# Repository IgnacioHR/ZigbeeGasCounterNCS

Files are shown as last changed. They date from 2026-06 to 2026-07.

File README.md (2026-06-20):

# Zigbee Gas Counter for nRF52840

This project is a DIY Zigbee gas counter based on the Nordic Semiconductor nRF52840 platform.

It measures gas consumption by detecting pulses from a mechanical gas meter using a reed sensor, keeps an internal cumulative counter, and exposes the data through Zigbee so it can be used from Zigbee2MQTT and Home Assistant.

The device is designed to run from batteries for long periods of time and to keep counting even if Zigbee2MQTT, Home Assistant, or the Zigbee coordinator are temporarily unavailable.

## Features

- Zigbee gas consumption tracking in cubic meters (m³).
- Internal cumulative counter stored by the device.
- Battery-powered low-power design.
- Zigbee radio enabled only when needed.
- Dual 18650 battery holder with batteries connected in parallel.
- Battery replacement without interrupting device operation.
- Battery voltage and battery percentage reporting.
- Main button with gesture recognition.
- Zigbee OTA firmware updates.
- MCUboot-based bootloader.
- Source code available for both:
  - Seeed Studio XIAO nRF52840
  - Nordic Semiconductor nRF52840 DK
- 3D-printable enclosure and battery holder.
- Optional gas flow measurement.
- Optional battery measurement and reporting.
- Configurable deep-sleep or light-sleep behavior.
- Optional manufacturer-specific attribute for setting the counter value.

## Hardware Pictures

### Fully assembled device

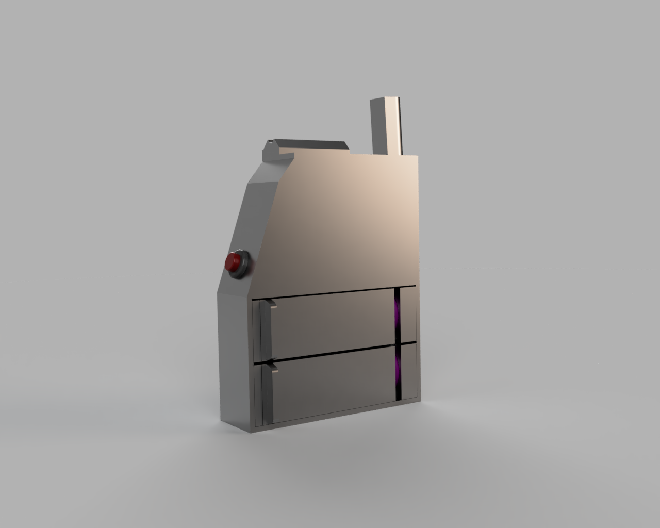
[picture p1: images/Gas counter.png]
Gas counter


### Cover removed

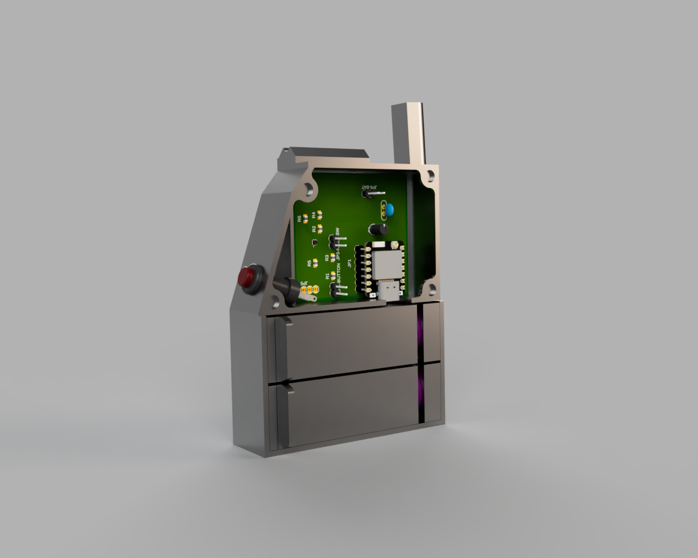
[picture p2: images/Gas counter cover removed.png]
Gas counter cover removed


### Cover removed and bottom battery extracted

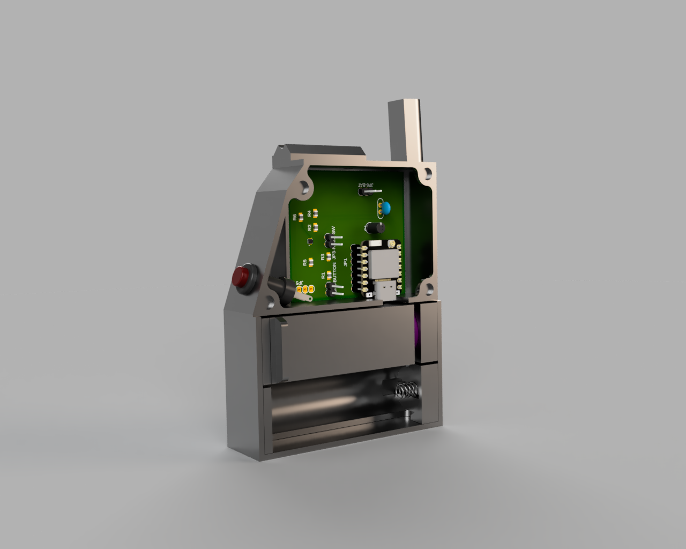
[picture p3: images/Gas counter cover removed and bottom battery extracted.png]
Gas counter cover removed and bottom battery extracted


## Supported Boards

This repository contains source code for two hardware targets.

### Seeed Studio XIAO nRF52840

This is the board used in the actual deployed gas counter device.

The XIAO nRF52840 version is optimized for low-power battery operation and is intended to be installed next to the gas meter inside the custom 3D-printed enclosure.

### Nordic Semiconductor nRF52840 DK

The nRF52840 DK version is used for development, debugging, and testing.

It is useful while developing new firmware features because it provides easier access to SWD, buttons, LEDs, and debug interfaces.

## Zigbee Device Type and Low-Power Operation

In a Zigbee network, devices are usually classified as coordinators, routers, or end devices.

This project behaves as a low-power end device, but with a very specific operating model: the Zigbee radio is normally kept off to save energy, and it is enabled only when needed.

In normal operation, the device wakes the Zigbee radio every 10 gas meter pulses. This allows the counter to keep accurate local measurements while avoiding the power cost of keeping the radio permanently active.

The device can also enable the Zigbee radio when the main button is pressed. This is useful before starting an OTA update, writing the counter value, or forcing an immediate report.

The nRF52840 does not include a dedicated real-time clock that can be used as an absolute wall-clock source while the device is sleeping. For this reason, the firmware uses time information obtained from the Zigbee coordinator to maintain internal timing-related state, such as calculating how long it has been since the battery was last measured.

## Bootloader and Firmware Updates

The firmware boots through MCUboot.

Because of this, the initial firmware must be programmed using an SWD programmer/debugger. Once the bootloader and the first application image have been written, future firmware updates can be performed over Zigbee OTA.

A typical deployment process is:

1. Build the firmware with MCUboot enabled.
2. Flash the complete merged image through SWD.
3. Pair the device with the Zigbee network.
4. Use Zigbee OTA for future firmware updates.

When using OTA, the new image is first downloaded through Zigbee, then MCUboot swaps the image on reboot. The new firmware confirms itself after it has successfully started and recovered Zigbee connectivity.

## How It Works

1. The gas meter has a rotating part with a magnet.
2. A reed sensor detects each rotation or pulse.
3. Each pulse represents a known gas volume.
4. The nRF52840 firmware updates the internal cumulative counter.
5. The device periodically enables the Zigbee radio and reports the accumulated data.
6. The device exposes the value through the Zigbee Metering cluster.
7. Zigbee2MQTT receives the data and forwards it to Home Assistant.

The device does not depend on Home Assistant being online in order to keep counting. The counter is maintained internally by the device.

## Main Button Gestures

The device has one main button. Multiple gestures are recognized and mapped to device actions.

### Button press

Pressing the button, even as part of another gesture, enables the Zigbee radio for approximately one minute and transmits the currently available data.

Use this before performing actions that require the device to be reachable, such as:

- Starting an OTA firmware update.
- Writing a new gas counter value from Zigbee2MQTT.
- Requesting immediate reports.

The Zigbee radio may take around 10 seconds to reconnect to the coordinator, so wait a short time after pressing the button before sending Zigbee commands.

### Single click

A single click is the most common user action.

It performs the following actions:

- Reports all reportable attributes, including gas counter and battery information.
- Forces a battery level measurement.
- Clears and reevaluates possible warning or fault conditions.

### Triple click

A triple click resets the device.

The gas counter value is not intentionally cleared by this action.

### Five quick clicks

Five quick button clicks make the device leave the current Zigbee network and start the join process again.

Use this when you want to move the device to another Zigbee network or force a clean rejoin.

## Battery System

The device uses two 18650 batteries connected in parallel.

The current prototype uses two 3400 mAh cells, providing a total nominal capacity of approximately 6800 mAh.

The enclosure and battery holder are designed so one battery can be removed and charged externally while the device continues running from the other battery.

Always keep at least one battery installed. This prevents the device from losing power and helps avoid missed gas meter pulses during battery replacement.

## Battery Life

The device is designed for very low power operation.

Battery voltage and percentage are measured and reported at least once every 12 hours. They can also be refreshed manually with a single button click.

With two 3400 mAh batteries connected in parallel, the expected runtime is several months. The final runtime is still being measured.

## Zigbee Integration

The device is intended to work with:

- Zigbee2MQTT
- Home Assistant

The firmware exposes gas consumption through standard Zigbee clusters where possible, while also using custom manufacturer-specific attributes for device-specific operations such as setting the current counter value.

The manufacturer information used by the device is:

- Manufacturer name: `Custom devices (DiY)`
- Model identifier: `MiCASAGasCounter`
- Manufacturer code: `0x8888`

The manufacturer code is arbitrary and intended for this DIY project.

## Setting the Counter Value

If enabled in `include/zb_features.h`, the firmware includes a manufacturer-specific attribute in the Metering cluster that allows the cumulative counter value to be set from Zigbee2MQTT.

This is useful when installing the device for the first time, because the internal counter can be synchronized with the physical gas meter reading.

Before writing the counter value, press the main button to wake the Zigbee radio and wait a few seconds for the device to reconnect.

## OTA Firmware Updates

The firmware supports Zigbee OTA updates.

Before starting an OTA update:

1. Press the main button.
2. Wait approximately 10 seconds for Zigbee connectivity to be restored.
3. Start the OTA update from Zigbee2MQTT.

After the OTA transfer completes, the device reboots. MCUboot then boots the new image. The firmware confirms the new image only after the device has started successfully and has had time to reconnect to the Zigbee network.

This reduces the risk of permanently confirming a firmware image that boots but cannot recover basic Zigbee functionality.

## Required Hardware

To build the XIAO-based version, you need:

- Seeed Studio XIAO nRF52840.
- Magnetic reed sensor.
- Two 18650 batteries.
- Battery contacts or battery holder hardware.
- Main push button.
- 3D-printed enclosure.
- SWD programmer/debugger for the initial firmware flash.
- 18 small magnets 4.75mm x 1.5mm (see the `hardware` folder)

For development, the Nordic Semiconductor nRF52840 DK can be used instead of the XIAO board.

## Software Requirements

- nRF Connect SDK.
- Zephyr RTOS.
- MCUboot.
- Zigbee2MQTT.
- Home Assistant, optional but recommended.
- SWD flashing/debugging tools.

## Configuration Options

Some firmware features can be enabled or disabled from:

```text
include/zb_features.h
```

The default configuration is tuned for my own use case: a battery-powered gas counter using deep sleep for maximum battery life.

If your use case is different, review this file before building the firmware.

### Gas flow measurement

The firmware can optionally expose gas flow measurement.

This requires more frequent Zigbee communication, so it is not recommended for battery-powered deployments. It can be useful if the device is externally powered or if battery life is not a concern.

### Battery measurement

Battery voltage and battery percentage reporting can be enabled or disabled.

If the device is not powered from batteries, this feature can be disabled.

### Deep sleep

Deep sleep provides the lowest power consumption.

This is the configuration used by my deployed device. In this mode, the device keeps counting locally and only enables the Zigbee radio when needed, such as after a configured number of gas meter pulses or when the main button is pressed.

This mode is recommended for long-term battery-powered operation.

### Light sleep

Light sleep implements a more conventional Zigbee end-device behavior.

In this mode, the device keeps the Zigbee radio enabled and does not enter deep sleep. This makes the device more readily available on the Zigbee network, but it consumes significantly more power.

This mode may be useful during development, testing, or externally powered deployments.

### Counter write attribute

The firmware includes an optional manufacturer-specific attribute that allows the gas counter value to be written from Zigbee2MQTT.

This is useful when installing the device because the internal counter can be synchronized with the physical gas meter reading.

If this feature is disabled, the counter value cannot be written remotely.

## Building and Flashing

The project is built with nRF Connect SDK and Zephyr.

The firmware uses MCUboot, so the first flash should write the complete merged image, not only the application image.

A typical SWD flashing process writes:

```bash
merged.hex
```

After the initial programming, future updates can be delivered using Zigbee OTA.

## 3D-Printed Hardware

The repository includes STEP files for the enclosure and battery holder.

The 3D-printed hardware is designed to hold:

- The main electronics board.
- Two 18650 batteries.
- The main button.
- The reed sensor.
- The removable cover.

The mechanical design is intended to make battery replacement possible without fully powering down the device.

## Project Status

This project is the nRF52840 evolution of the original ESP32-C6 Zigbee gas counter.

The ESP32-C6 version proved the concept and helped validate the Zigbee gas counter design. The nRF52840 version focuses on improving power consumption, OTA robustness, and long-term reliability.

Current status:

- Pulse counting works.
- Zigbee integration works.
- Battery reporting works.
- Main button gesture handling works.
- Zigbee OTA works.
- MCUboot image confirmation is handled by the application after startup.
- Long-term battery life is still being measured.

## Relation to the ESP32-C6 Version

This project is based on lessons learned from the previous ESP32-C6 implementation.

The ESP32-C6 version proved the concept and helped validate the Zigbee gas counter design. The nRF52840 version focuses on improving power consumption, OTA robustness, and long-term reliability.

## Customization

The same approach can be adapted to other pulse-based meters, such as:

- Water meters.
- Electricity meters with pulse output.
- Other mechanical counters with a magnet or reed-compatible pulse source.

The main changes would be the unit of measurement, the pulse-to-volume conversion factor, and the Zigbee attributes exposed by the firmware.

## Contributing

Contributions, suggestions, and improvements are welcome.

Areas where contributions may be useful include:

- Reviewing the low-power design.
- Improving Zigbee2MQTT converter support.
- Reviewing hardware design.
- Testing other reed sensors or enclosure variants.
- Improving documentation.

## Acknowledgments

I would like to thank Nordic Semiconductor for the excellent online training courses and documentation. They helped me start development on the nRF52840 platform much faster than I expected.

I also want to acknowledge the invaluable help of ChatGPT during the development process. It helped me move faster, debug complex issues, and explore solutions while building this project.

## License

This project is shared under the Creative Commons Attribution-NonCommercial-ShareAlike 4.0 International License.

You are free to copy, modify, and adapt the project for personal or non-commercial use, provided that you give appropriate credit and share derived work under the same license.

Commercial use is not allowed.

See the license details here:

[Creative Commons Attribution-NonCommercial-ShareAlike 4.0 International](https://creativecommons.org/licenses/by-nc-sa/4.0/deed.en)

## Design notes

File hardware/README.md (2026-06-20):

# Hardware

This directory contains the 3D-printable parts used to assemble the gas counter enclosure.

The enclosure is designed to hold:

- The main electronics board
- Two 18650 batteries connected in parallel
- The main push button
- The reed sensor used to detect gas meter pulses

The main body has an opening at the top for inserting a 5 mm × 10 mm threaded insert, which is used to attach the enclosure to the gas meter. The triangular-looking part with a cylindrical section in the middle is designed to hold the reed sensor in the correct position.

## Power Source

The device is powered by two 18650 batteries connected in parallel.

The reason for using two batteries is to make battery maintenance easier: one battery can be removed and charged externally while the device continues running from the other battery.

Always keep at least one battery installed while replacing or charging the other one. This prevents the device from losing power and helps ensure that no reed sensor pulses are missed during battery maintenance.

## Materials

All parts were printed in PETG.

PETG was chosen because it provides a good balance between mechanical strength, durability, and ease of printing.

## Magnets

Some parts include small cylindrical holes measuring approximately 4.75 mm × 1.65 mm. These holes are intended for small magnets.

The magnets are used to hold the battery holder, main body, and cover plate together without requiring screws for those parts.

## License

The models are shared in STEP format so they can be adapted to different setups or modified for your own needs.

These hardware models are licensed under the **Creative Commons Attribution-NonCommercial-ShareAlike 4.0 International License**.

You are free to copy, modify, and adapt the models for personal or non-commercial use, provided that you give appropriate credit and share any derived work under the same license.

Commercial use is not allowed.

## Downloads

- [Gas counter - Main body](Gas%20counter%20main%20body.step)
- [Gas counter - Top cover](Gas%20counter%20top%20cover.step)
- [Battery holder - Top side](Battery%20holder%20-%20top%20side.step)
- [Battery holder - Bottom side](Battery%20holder%20-%20bottom%20side.step)
- [Battery holder - Lock for hole under negative pole](Battery%20holder%20-%20lock%20for%20hole%20under%20negative%20pole.step)
- [Battery holder - Lock for hole under positive pole](Battery%20holder%20-%20lock%20for%20hole%20under%20positive%20pole.step)

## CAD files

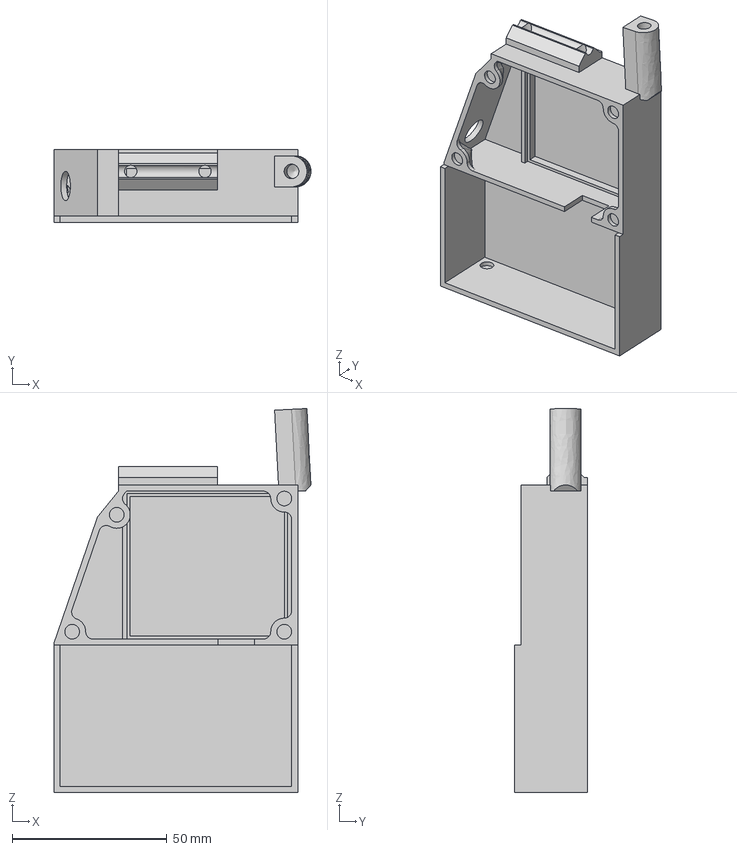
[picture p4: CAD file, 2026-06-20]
hardware/Gas counter main body.step
83.1 x 23.4 x 124.1 mm

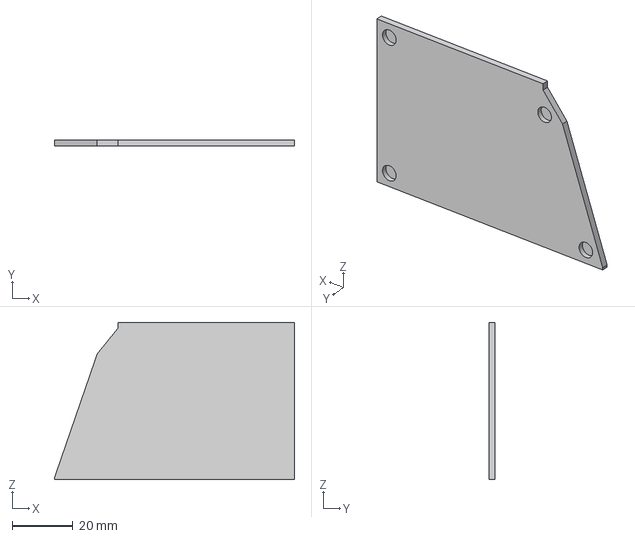
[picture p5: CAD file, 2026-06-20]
hardware/Gas counter top cover.step
78.8 x 2.00 x 51.7 mm

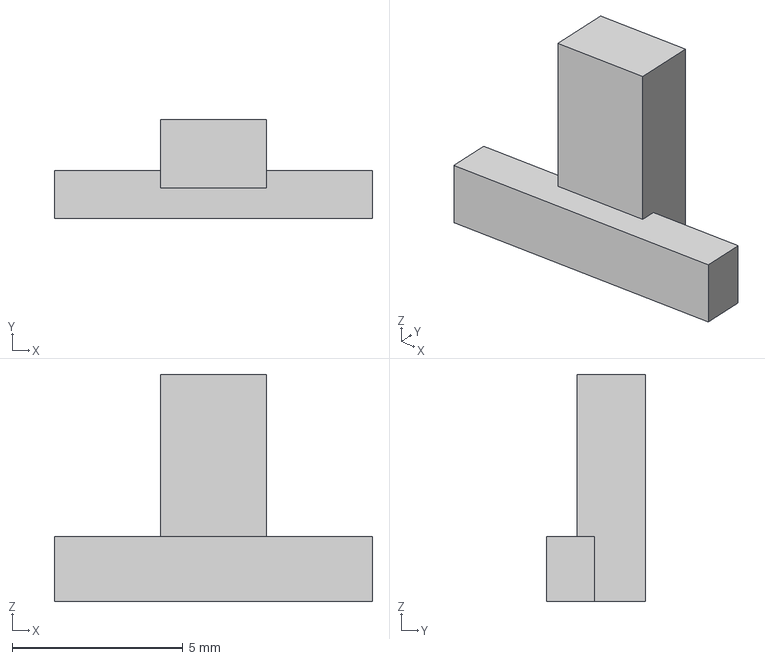
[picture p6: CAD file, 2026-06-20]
hardware/Battery holder - lock for hole under positive pole.step
9.30 x 2.90 x 6.65 mm

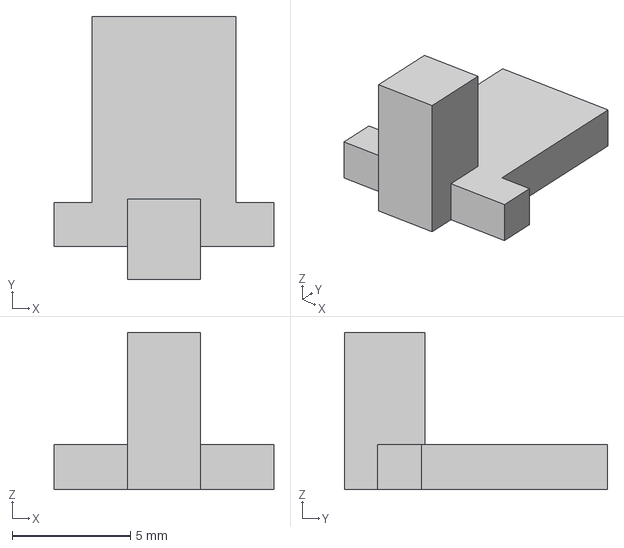
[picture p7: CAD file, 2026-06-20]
hardware/Battery holder - lock for hole under negative pole.step
9.30 x 11.1 x 6.65 mm

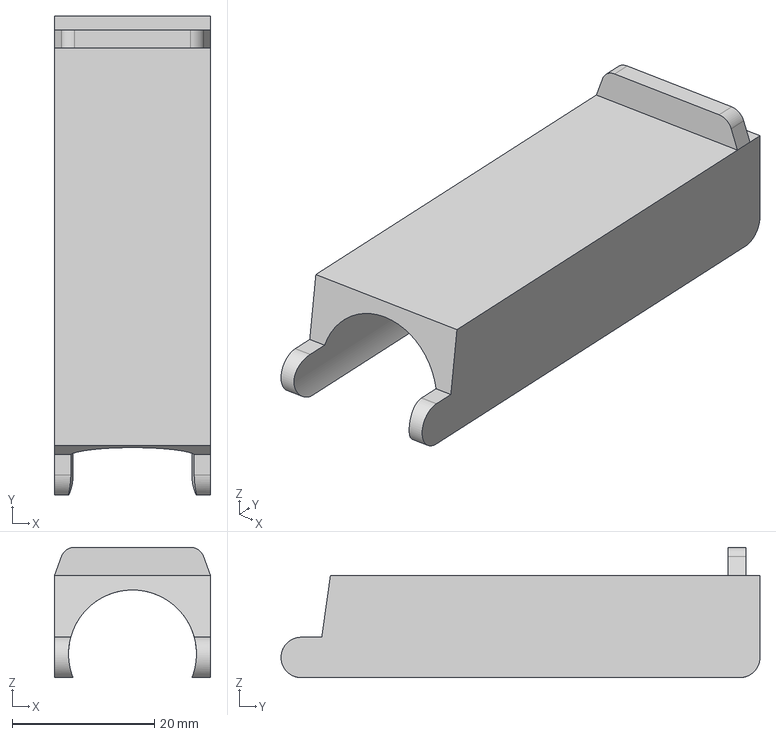
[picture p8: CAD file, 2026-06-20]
hardware/Battery holder - top side.step
22.0 x 67.4 x 18.4 mm

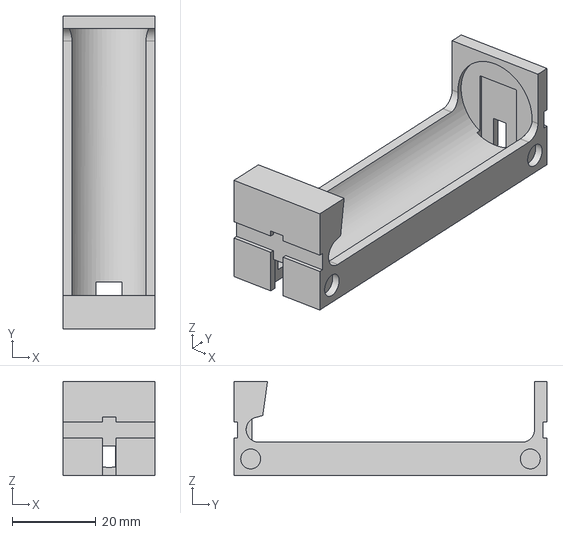
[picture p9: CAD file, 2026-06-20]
hardware/Battery holder - bottom side.step
22.0 x 74.6 x 22.5 mm

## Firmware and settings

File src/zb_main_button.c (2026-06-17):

/*
 * Zigbee Gas Counter - An open-source Zigbee gas counter project.
 * Copyright (c) 2026 Ignacio Hernández-Ros.
 *
 * This work is licensed under the Creative Commons Attribution-NonCommercial-ShareAlike 4.0
 * International License. To view a copy of this license, visit
 * https://creativecommons.org/licenses/by-nc-sa/4.0/
 *
 * You may use, modify, and share this work for personal and non-commercial purposes, as long
 * as you credit the original author(s) and share any derivatives under the same license.
 */

#include <zephyr/kernel.h>
#include <zephyr/device.h>
#include <zephyr/devicetree.h>
#include <zephyr/drivers/gpio.h>
#include <zephyr/sys/reboot.h>

#include <zephyr/logging/log.h>
LOG_MODULE_REGISTER(btn_main, LOG_LEVEL_INF);

#include <zephyr/logging/log_ctrl.h>

#include "zb_features.h"
#include "zb_main_button.h"
#include "zb_main_loop.h"
#include "zb_deep_sleep.h"
#include "zb_report_event.h"
#include "zb_zigbee.h"
#include "zb_zigbee_ctx.h"
#include "zb_gpio_stable.h"
#include "zb_led.h"

#ifdef FEATURE_DEEP_SLEEP
static atomic_t started_from_deep_sleep = ATOMIC_INIT(false);
#endif

/** Hardware from device tree */
#define MAIN_BUTTON_NODE DT_ALIAS(main_button)
static const struct gpio_dt_spec main_button = GPIO_DT_SPEC_GET(MAIN_BUTTON_NODE, gpios);

#ifdef CONFIG_DEBUG
#define LED0_NODE DT_ALIAS(led0)
static const struct gpio_dt_spec led_main_button = GPIO_DT_SPEC_GET(LED0_NODE, gpios);
#endif

/** Thread stacks and priorities */
#define BTN_THREAD_STACK_SIZE    1024
#define BTN_THREAD_PRIORITY         5
#define BTN_TASK_STACK_SIZE      2048
#define BTN_TASK_PRIORITY           5

// Hardware debounce time of the main button switch
#define BTN_DEBOUNCE_TIMEOUT 30 /* milliseconds */

// How long does the chip take from the moment it wakes up from an interrupt to the moment the button release time timer is computed */
// This value must be measured in place using the log facilities
#define FIXED_START_TIME_MS				150

#define CLICK_PRESS_TIME_MS       400    // MUST BE BIGGER THAN "FIXED_START_TIME_MS"
#define CLICK_HOLD_TIME_MS       3000
#define CLICK_RELEASE_TIME_MS     200

/** Main button gestures recognized */
typedef enum ButtonState_e {
    NONE = 0,
    PRESS,
    RELEASE,
    SINGLE_CLICK,
    DOUBLE_CLICK,
		TRIPLE_CLICK,
		CUADRUPLE_CLICK,
		QUINTUPLE_CLICK,
    UNKNOWN_CLICK,
    HOLD
} button_state_msg_t;

static atomic_t button_state = ATOMIC_INIT(NONE);

static K_SEM_DEFINE(btn_press_sem, 0, K_SEM_MAX_LIMIT);
static K_SEM_DEFINE(btn_release_sem, 0, K_SEM_MAX_LIMIT);

int main_button_read_early_level(void)
{
	int err;
	if (!device_is_ready(main_button.port)) {
		return -ENODEV;
	}
	err = gpio_pin_configure_dt(&main_button, GPIO_INPUT);
	if (err < 0) {
		return err;
	}
	return gpio_pin_get_dt(&main_button);
}

int main_button_read_stable_level(void)
{
	return gpio_read_stable_level(&main_button, 5, K_MSEC(10));
}

#ifdef FEATURE_DEEP_SLEEP
/**
 * @brief Safe way to set this property from other threads
 * 
 * @param value 
 */
void set_started_from_deep_sleep(bool value)
{
	atomic_set(&started_from_deep_sleep, false);
}
#endif

/**
 * @brief Callback from the ISR the main button has been pressed or released
 * 
 * @param dev N/A
 * @param cb N/A
 * @param pins N/A
 */
static void main_button_isr_cb(const struct device *dev, struct gpio_callback *cb, uint32_t pins)
{
	ARG_UNUSED(dev);
	ARG_UNUSED(cb);
	ARG_UNUSED(pins);

	static int64_t last_main_btn_time_ms;

	int64_t now = k_uptime_get();
	const int64_t diff_ms = now - last_main_btn_time_ms;

	if ((last_main_btn_time_ms > 0) && (diff_ms <= BTN_DEBOUNCE_TIMEOUT)) {
		return;
	}

	const int level = gpio_pin_get_dt(&main_button);
	if (level < 0)
		return;
	
	button_state_msg_t state = (button_state_msg_t)atomic_get(&button_state);

	if ((level == 1) && (state != PRESS)) {
#ifdef FEATURE_DEEP_SLEEP
		set_started_from_deep_sleep(false);
#endif
		k_sem_give(&btn_press_sem);
	}
	if ((level == 0) || (state == PRESS)) {
		k_sem_give(&btn_release_sem);
	}

	last_main_btn_time_ms = now;

#ifdef CONFIG_DEBUG
	gpio_pin_set_dt(&led_main_button, level);
#endif
}

static int main_button_configure(int *level)
{
	int err;

	if (!device_is_ready(main_button.port)) {
		LOG_ERR("Main button GPIO device not ready");
		return -ENODEV;
	}

	err = gpio_pin_configure_dt(&main_button, GPIO_INPUT);
	if (err < 0) {
		LOG_ERR("GPIO can't configure main button (err: %d)", err);
		return err;
	}

	err = gpio_pin_interrupt_configure_dt(&main_button, GPIO_INT_EDGE_BOTH);
	if (err < 0) {
		LOG_ERR("GPIO can't configure main button interrupt (err: %d)", err);
		return err;
	}

	static struct gpio_callback main_button_cb_data;
	gpio_init_callback(&main_button_cb_data, main_button_isr_cb, BIT(main_button.pin));
	*level = gpio_pin_get_dt(&main_button);
	err = gpio_add_callback(main_button.port, &main_button_cb_data);
	if (err < 0) {
		LOG_ERR("GPIO can't add callback of main button interrupt (err: %d)", err);
	}

	LOG_DBG("Main button initialized");
	return 0;
}

/**
 * @brief Programatically initiates the process of button press normally fired by the interruption
 * 
 */
void main_button_fire_press(void)
{
	k_sem_give(&btn_press_sem);
}

/**
 * @brief Programatically initiates the process of button release normally fired by the interruption
 * 
 */
void main_button_fire_release(void)
{
	k_sem_give(&btn_release_sem);
}

/**
 * @brief Configure GPIO to wake up the device.
 * 
 */
int main_button_gpio_wakeup(void)
{
	int current;

	if (!device_is_ready(main_button.port)) {
		LOG_ERR("Main button GPIO device not ready");
		return -ENODEV;
	}

	current = main_button_read_early_level();
	if (current < 0) {
		return current;
	}

	if (current == 1) {
		LOG_WRN("main_button_gpio_wakeup: button already active");
		return -EAGAIN;
	}

	return gpio_pin_interrupt_configure_dt(&main_button, GPIO_INT_LEVEL_ACTIVE);
}

#ifdef CONFIG_DEBUG
/**
 * @brief Hardware configuration of the led associated with the main button
 * 
 * @return int 
 */
static int main_button_led_configure(void)
{
	int err = gpio_pin_configure_dt(&led_main_button, GPIO_OUTPUT_ACTIVE);
	if (err < 0) {
		LOG_ERR("GPIO can't configure main button led (err: %d)", err);
		return err;
	}
	return 0;
}
#endif

/**
 * @brief Hardware configuration of the main button input gpio pin and interrupt
 * @param level stores the pin level prior to setup the interrupt
 * 
 * @return int 
 */
int main_button_gpio_init(int *level)
{
	int err;
	err = main_button_configure(level);
	if (err < 0)
		return err;
#ifdef CONFIG_DEBUG
	err = main_button_led_configure();
	if (err < 0)
		return err;
#endif
	return 0;
}

// Message queue for main button state changes
K_MSGQ_DEFINE(btn_state_msgq, sizeof(button_state_msg_t), 1, 1);

// Required inside btn_notify_state
static K_MUTEX_DEFINE(btn_notify_mutex);

/**
 * @brief changes the internal button state and fires message to the queue
 * 
 * @param state new state to assign
 * @return button_state_msg_t same state assigned, for convenience, see usage
 */
static button_state_msg_t btn_notify_state(button_state_msg_t state)
{
	button_state_msg_t msg = (button_state_msg_t)state;
	k_mutex_lock(&btn_notify_mutex, K_FOREVER);
	atomic_set(&button_state, state);
	if (k_msgq_num_used_get(&btn_state_msgq) > 0)
		k_msgq_purge(&btn_state_msgq);
	int err = k_msgq_put(&btn_state_msgq, &msg, K_NO_WAIT);
	k_mutex_unlock(&btn_notify_mutex);
	if (err != 0) {
			LOG_ERR("Cannot notify button state: %d", err);
	}
	return state;
}

/**
 * @brief called when timer expires after main button press action detected, note, this timer
 * is cancelled if a release action is detected within CLICK_PRESS_TIME_MS milliseconds.
 * Allows to detect UNKNOWN_CLICK action detection.
 * 
 * @param work 
 */
static void timer_since_press_cb(struct k_work *work)
{
	ARG_UNUSED(work);
	button_state_msg_t state = (button_state_msg_t)atomic_get(&button_state);

	if (
		state == SINGLE_CLICK || 
		state == DOUBLE_CLICK || 
		state == TRIPLE_CLICK || 
		state == CUADRUPLE_CLICK || 
		state == QUINTUPLE_CLICK || 
		state == UNKNOWN_CLICK
	) {
		btn_notify_state(UNKNOWN_CLICK);
	}
}
static K_WORK_DELAYABLE_DEFINE(work_since_press, timer_since_press_cb);

/**
 * @brief called when the timer expires after main button press action detected, note, this timer
 * is cancelled if a release action is detected. Allows to detect HOLD o long press actions.
 * 
 * @param work 
 */
static void timer_since_press_detect_hold_cb(struct k_work *work)
{
	ARG_UNUSED(work);
	button_state_msg_t state = (button_state_msg_t)atomic_get(&button_state);
	if (state == PRESS)
		btn_notify_state(HOLD);
}
static K_WORK_DELAYABLE_DEFINE(work_detect_hold, timer_since_press_detect_hold_cb);

/**
 * @brief called when the timer expires after main button release action detected, note, this timer
 * is cancelled if a press action is detected within the period of time defined at CLICK_RELEASE_TIME_MS. 
 * Allows to announce proper gesture detected
 * 
 * @param work 
 */
static void timer_since_release_cb(struct k_work *work)
{
	ARG_UNUSED(work);
	button_state_msg_t state = (button_state_msg_t)atomic_get(&button_state);
	bool valid_click = 
		state == SINGLE_CLICK || 
		state == DOUBLE_CLICK || 
		state == TRIPLE_CLICK || 
		state == CUADRUPLE_CLICK || 
		state == QUINTUPLE_CLICK || 
		state == UNKNOWN_CLICK;
	if (valid_click) {
		btn_notify_state(state);
	} else if (state != NONE) {
		btn_notify_state(HOLD);
	}
}
static K_WORK_DELAYABLE_DEFINE(work_since_release, timer_since_release_cb);

/**
 * @brief Called from the ISR when the button is pressed via a semaphore
 * 
 * @param p1 
 * @param p2 
 * @param p3 
 */
static void btn_press_thread(void *p1, void *p2, void *p3)
{
	int err;
	ARG_UNUSED(p1);
	ARG_UNUSED(p2);
	ARG_UNUSED(p3);

	LOG_DBG("Main button press thread started");
	while (true) {
		k_sem_take(&btn_press_sem, K_FOREVER);

		button_state_msg_t state = (button_state_msg_t)atomic_get(&button_state);

		if (state == NONE) {
			state = btn_notify_state(PRESS);
		}
		
		int32_t click_press_time_adjusted_ms = CLICK_PRESS_TIME_MS;			
		int32_t hold_time_adjusted_ms = CLICK_HOLD_TIME_MS;
		#ifdef FEATURE_DEEP_SLEEP
		bool started_from_deep_sleep_value = atomic_get(&started_from_deep_sleep);
		if (started_from_deep_sleep_value)
		{
				int32_t startTime_ms = FIXED_START_TIME_MS; // empirical evaluation needed
				// substract FIXED_START_TIME_MS ms to timers
				click_press_time_adjusted_ms = click_press_time_adjusted_ms - startTime_ms; // measured time for the device to start
				hold_time_adjusted_ms -= hold_time_adjusted_ms - startTime_ms;
		}
		#endif
		err = k_work_reschedule(&work_since_press, K_MSEC(click_press_time_adjusted_ms));
		if (err < 0)
			LOG_ERR("Can't set press timer time to %dms", click_press_time_adjusted_ms);
		if (state == PRESS) {
			err = k_work_reschedule(&work_detect_hold, K_MSEC(hold_time_adjusted_ms));
			if (err < 0)
				LOG_ERR("Can't start hold timer");
		} else {
			err = k_work_cancel_delayable(&work_since_release);
			if (err < 0)
				LOG_ERR("Can't stop press timer: %d", err);
		}
	}
}
static K_THREAD_DEFINE(btn_press_tid, BTN_THREAD_STACK_SIZE, btn_press_thread, NULL, NULL, NULL, BTN_THREAD_PRIORITY, 0, K_TICKS_FOREVER);

/**
 * @brief Called from the ISR when the button is released via a semaphore
 * 
 * @param p1 
 * @param p2 
 * @param p3 
 */
static void btn_release_thread(void *p1, void *p2, void *p3)
{
	int err;
	ARG_UNUSED(p1);
	ARG_UNUSED(p2);
	ARG_UNUSED(p3);

	LOG_INF("Main button release task started");
	while (true)
	{
		k_sem_take(&btn_release_sem, K_FOREVER);

		button_state_msg_t state = (button_state_msg_t)atomic_get(&button_state);

		if (state == PRESS) {
			state = btn_notify_state(RELEASE);
		}
		if (state == HOLD) {
			state = btn_notify_state(NONE);
			continue;
		}
		if (k_work_delayable_is_pending(&work_since_press)) {
			err = k_work_cancel_delayable(&work_since_press);
			if (err < 0)
				LOG_ERR("Can't cancel work_since_press timer");
			if (state == SINGLE_CLICK) {
				atomic_set(&button_state, DOUBLE_CLICK);
			} else if (state == DOUBLE_CLICK) {
				atomic_set(&button_state, TRIPLE_CLICK);
			} else if (state == TRIPLE_CLICK) {
				atomic_set(&button_state, CUADRUPLE_CLICK);
			} else if (state == CUADRUPLE_CLICK) {
				atomic_set(&button_state, QUINTUPLE_CLICK);
			} else if (state == QUINTUPLE_CLICK) {
				atomic_set(&button_state, UNKNOWN_CLICK);
			} else if (
				state != UNKNOWN_CLICK && 
				state != DOUBLE_CLICK && 
				state != TRIPLE_CLICK &&
				state != CUADRUPLE_CLICK &&
				state != QUINTUPLE_CLICK
			) {
				atomic_set(&button_state, SINGLE_CLICK);
			}
		}
		if (k_work_delayable_is_pending(&work_detect_hold)) {
			err = k_work_cancel_delayable(&work_detect_hold);
			if (err < 0)
				LOG_ERR("Can't cancel work_detect_hold timer");
		}
		err = k_work_reschedule(&work_since_release, K_MSEC(CLICK_RELEASE_TIME_MS));
		if (err < 0)
			LOG_ERR("Can't start 0.4s timer after release");
	}
}
static K_THREAD_DEFINE(btn_release_tid, BTN_THREAD_STACK_SIZE, btn_release_thread, NULL, NULL, NULL, BTN_THREAD_PRIORITY, 0, K_TICKS_FOREVER);

/**
 * @brief process messages received int he button message queue. Allows to link gestures to specific actions
 * 
 * @param p1 
 * @param p2 
 * @param p3 
 */
static void btn_task(void *p1, void *p2, void *p3)
{
	int err;
	ARG_UNUSED(p1);
	ARG_UNUSED(p2);
	ARG_UNUSED(p3);
	LOG_INF("Main button action task started");
	while (true) {
		button_state_msg_t msg;
		err = k_msgq_get(&btn_state_msgq, &msg, K_FOREVER);
		if (err == -ENOMSG) {
			continue;
		}
		if (err < 0) {
			LOG_ERR("btn_task k_msgq_get (err: %d)", err);
			continue;
		}
		button_state_msg_t state = (button_state_msg_t)msg;
		switch (state) {
		case PRESS:
			// LOG_INF("Button press");
#ifdef CONFIG_DEBUG
			gpio_pin_set_dt(&led_main_button, 1);
#endif
#if HAS_XIAO_RGB_LED && IS_ENABLED(CONFIG_DEBUG)
      xiao_led_red_set(true);
#endif
			main_loop_post(SHALL_ENABLE_ZIGBEE);
#ifdef FEATURE_DEEP_SLEEP
			poweroff_mgr_user_window_extend(deep_sleep_eval_time_ms(true, false));
#endif
			break;
		case RELEASE:
			// LOG_INF("Button release");
#ifdef CONFIG_DEBUG
			gpio_pin_set_dt(&led_main_button, 0);
#endif
#if HAS_XIAO_RGB_LED && IS_ENABLED(CONFIG_DEBUG)
      xiao_led_red_set(false);
#endif
			break;
		case SINGLE_CLICK:
			LOG_INF("Single click detected");
			report_event_post(
				REPORT_CURRENT_SUMMATION_DELIVERED |
				REPORT_STATUS |
				REPORT_EXTENDED_STATUS
			);
#ifdef FEATURE_MEASURE_BATTERY_LEVEL
			main_loop_post(SHALL_MEASURE_BATTERY);
#endif
			reset_device_status();
			reset_device_extended_status();
			btn_notify_state(NONE);
			break;
		case DOUBLE_CLICK:
			LOG_INF("Double click detected");
			btn_notify_state(NONE);
			break;
		case TRIPLE_CLICK:
			LOG_INF("Triple click detected - reboot");
			btn_notify_state(NONE);
#if (IS_ENABLED(CONFIG_LOG))
			log_panic();
#endif
			sys_reboot(SYS_REBOOT_COLD);
			break;
		case CUADRUPLE_CLICK:
			LOG_INF("Cuadruple click detected");
			btn_notify_state(NONE);
			break;
		case QUINTUPLE_CLICK:
			LOG_INF("Quintuple click detected - leave");
			btn_notify_state(NONE);
			leave_action();
			break;
		case UNKNOWN_CLICK:
			LOG_INF("Unknown click detected");
			btn_notify_state(NONE);
			break;
		case HOLD:
			LOG_INF("Hold detected");
			break;
		case NONE:
			break;
		default:
			LOG_INF("Unknown button state: %d", state);
			break;
		}
	}
}
static K_THREAD_DEFINE(btn_task_tid, BTN_TASK_STACK_SIZE, btn_task, NULL, NULL, NULL, BTN_TASK_PRIORITY, 0, K_TICKS_FOREVER);

void main_button_start(void)
{
	k_thread_start(btn_press_tid);
	k_thread_start(btn_release_tid);
	k_thread_start(btn_task_tid);
}

/**
 * @brief Get the logical level of the main button input
 * 
 * @return int 
 */
int main_button_get_level(void)
{
	return gpio_pin_get_dt(&main_button);
}

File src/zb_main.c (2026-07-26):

/*
 * Zigbee Gas Counter - An open-source Zigbee gas counter project.
 * Copyright (c) 2026 Ignacio Hernández-Ros.
 *
 * This work is licensed under the Creative Commons Attribution-NonCommercial-ShareAlike 4.0
 * International License. To view a copy of this license, visit
 * https://creativecommons.org/licenses/by-nc-sa/4.0/
 *
 * You may use, modify, and share this work for personal and non-commercial purposes, as long
 * as you credit the original author(s) and share any derivatives under the same license.
 */

#include <zephyr/kernel.h>
#include <zephyr/device.h>
#include <zephyr/devicetree.h>
#include <zephyr/drivers/gpio.h>
#include <zephyr/logging/log.h>
LOG_MODULE_REGISTER(main, LOG_LEVEL_INF);

#include <zephyr/logging/log_ctrl.h>
#include <zephyr/drivers/hwinfo.h>
#include <zephyr/sys/poweroff.h>
#include <zephyr/sys/reboot.h>

#include <zboss_api.h>

#include <zigbee/zigbee_error_handler.h>
#include <zigbee/zigbee_app_utils.h>

#include <zb_nrf_platform.h>
#include <hal/nrf_power.h>
#include <ram_pwrdn.h>

#include "zb_features.h"
#include "zb_main_button.h"
#include "zb_zigbee.h"
#include "zb_zigbee_ctx.h"
#include "zb_main_loop.h"
#include "zb_nvr.h"
#include "zb_adc.h"
#include "zb_wakeup_cause.h"
#include "zb_report_event.h"
#include "zb_retained.h"
#include "zb_reed.h"
#include "zb_deep_sleep.h"
#include "zb_xiao.h"
#include "zb_ota.h"

static gm_wakeup_cause_t wakeup_cause;

gm_wakeup_cause_t get_wakeup_cause(void)
{
	return wakeup_cause;
}

static int configure_gpio(int *main_button_level, int *reed_level)
{
	int err;

	xiao_battery_frontend_disable();

	err = main_button_gpio_init(main_button_level);
	if (err < 0)
		return err;
	err = reed_gpio_init(reed_level);
	if (err < 0)
		return err;

#ifdef FEATURE_MEASURE_BATTERY_LEVEL
	err = adc_gpio_init();
	if (err < 0)
		return err;
#endif
#if HAS_XIAO_RGB_LED && IS_ENABLED(CONFIG_DEBUG)
	err = xiao_leds_init();
	if (err < 0)
		return err;
#endif

	return 0;
}

static bool wakeup_cause_requires_radio(gm_wakeup_cause_t wakeup_cause)
{
	return wakeup_cause == GM_WAKEUP_OTHER ||
	       wakeup_cause == GM_WAKEUP_GPIO_MAIN_BTN_PRESS;
}

static bool reed_inactive_requires_radio(uint64_t *not_reported)
{
	uint64_t current;
	uint64_t last;

	nvr_ensure_loaded();

	current = get_current_summ();
	last = retained_get_last_summation_sent();

	*not_reported = current - last;

	if (*not_reported >= COUNTER_REPORT_DIFF) {
		LOG_INF("Radio shall be started due to counter rebased max difference current=%lld last=%lld",
			current, last);
		return true;
	}

	return false;
}

static void start_radio_and_report(bool main_button)
{
	main_loop_post(SHALL_ENABLE_ZIGBEE);
	report_event_post(REPORT_CURRENT_SUMMATION_DELIVERED);
#ifdef FEATURE_DEEP_SLEEP
	poweroff_mgr_user_window_extend(deep_sleep_eval_time_ms(main_button, !main_button));
#endif
}

static void log_radio_not_needed_for_reed_inactive(uint64_t not_reported)
{
	int remaining = COUNTER_REPORT_DIFF - not_reported;

	LOG_INF("Still %d pulses remaining to start radio", remaining);
}

static void check_shall_enable_radio(gm_wakeup_cause_t wakeup_cause, bool b_missed_reed)
{
	uint64_t not_reported = 0;
	bool enable_radio;

	enable_radio = wakeup_cause_requires_radio(wakeup_cause);

	if (wakeup_cause == GM_WAKEUP_GPIO_REED_PULSE_INACTIVE || b_missed_reed) {
		enable_radio = reed_inactive_requires_radio(&not_reported);
	} else if (enable_radio) {
		LOG_INF("Radio shall be started due to wakeup_cause");
	}

	if (enable_radio) {
		start_radio_and_report(wakeup_cause == GM_WAKEUP_GPIO_MAIN_BTN_PRESS);
		return;
	}

	if (wakeup_cause == GM_WAKEUP_GPIO_REED_PULSE_INACTIVE || b_missed_reed) {
		log_radio_not_needed_for_reed_inactive(not_reported);
	}
}

static bool is_reed_wakeup_cause(gm_wakeup_cause_t wakeup_cause)
{
	return wakeup_cause == GM_WAKEUP_GPIO_REED_PULSE_INACTIVE || wakeup_cause == GM_WAKEUP_GPIO_REED_PULSE_ACTIVE;
}

int poweroff(void) {
	int err;
	err = retained_set_boot_to_system_off(false);
	if (err != 0) {
		LOG_ERR("Can't set retained to system off to false (err: %d)", err);
		return err;
	}

	err = main_button_gpio_wakeup();
	if (err != 0) {
		LOG_ERR("Can't configure main button for wakeup (err: %d)", err);
		return err;
	}
	err = reed_gpio_wakeup(); // Internally this is calling retained_flush_sync();
	if (err != 0) {
		LOG_ERR("Can't configure reed for wakeup (err: %d)", err);
		return err;
	}
	if (err == 0) {
		LOG_INF("Powering off now");
#if (IS_ENABLED(CONFIG_LOG))
		log_panic();
#endif
		sys_poweroff();
	}
	return 0;
}

int main(void)
{
	int err;

	LOG_DBG("Starting Zigbee Gas Counter");

	// set ctx initial values before zigbee radio is started so values can be changed anytime from this moment if needed
	retained_init();

	if (IS_ENABLED(CONFIG_RAM_POWER_DOWN_LIBRARY)) {
		power_down_unused_ram();
	}

	// app_confirm_mcuboot_image();
	bool ota_new_image = ota_is_new_image();

	if (!ota_new_image && retained_shall_power_off()) {
		LOG_DBG("Requesting WDT reset before system_off path");
		err = poweroff();
		if (err != 0) {
			sys_reboot(SYS_REBOOT_COLD);
		}
		CODE_UNREACHABLE;
	}

	app_device_ctx_init();

	int main_button_level;
	int reed_level;
	err = configure_gpio(&main_button_level, &reed_level);
	if (err < 0) {
		return err;
	}

	err = detect_cause_init();
	if (err != 0) {
		LOG_WRN("detect_cause_init returned %d", err);
	}

	wakeup_cause = wakeup_cause_init();
#ifdef FEATURE_DEEP_SLEEP
	poweroff_mgr_enable_for_wakeup(wakeup_cause);
#endif
	// check for missing interrupts, happens if the user releases the button prior to setting up
	// the interrupts
	if (wakeup_cause == GM_WAKEUP_GPIO_MAIN_BTN_PRESS && main_button_level == 0) {
		// the user pressed the button, device was wake up but the user released the button
		// and the interrupt has not been able to catch. so fire event manually now
		main_button_fire_release();
	}
	bool b_missed_reed = false;
	// LOG_INF("wakeup_cause = %d reed_level = %d", wakeup_cause, reed_level);
	if (wakeup_cause == GM_WAKEUP_GPIO_REED_PULSE_ACTIVE && reed_level == 0) {
		// the user has release the button and we missed the event
		b_missed_reed = true;
	}	
	if (wakeup_cause == GM_WAKEUP_GPIO_REED_PULSE_INACTIVE || b_missed_reed)
		check_counter_increment();

	if (!is_reed_wakeup_cause(wakeup_cause)) {
 		main_button_start();
	}
	if (!ota_new_image) {
		check_shall_enable_radio(wakeup_cause, b_missed_reed);
	} else {
		start_radio_and_report(true);
	}
	LOG_DBG("Zigbee Gas Counter started");

#ifdef CONFIG_DEBUG
	reed_led_off();
#endif

	// if main loop has not started we can safely sleep now
	if (!is_main_loop_started()) {
		LOG_INF("Powering off now: direct system_off path");
		err = poweroff();
		if (err != 0) {
			sys_reboot(SYS_REBOOT_COLD);
		}
	}

#ifdef FEATURE_DEEP_SLEEP
	poweroff_mgr_block_clear(POF_BLOCK_APP_NOT_READY);
	poweroff_mgr_try_poweroff_now();
#endif
	return 0;
}

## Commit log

2026-05-30 able to fire adc measures
2026-05-30 adc works
2026-05-31 before testing adc
2026-05-31 adc final tuning
2026-06-02 do not panix, just reboot
    [zb_main.c]
2026-06-03 prior to test internal adc and pulldown
2026-06-17 ota confirm new version version information more dynamic led support if needed (normally disabled)
2026-06-20 documentation improvements
    [Battery holder - bottom side.step, Battery holder - lock for hole under negative pole.step, Battery holder - lock for hole under positive pole.step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]
2026-07-26 Separate current_summ_delivered to local variable and lock it when operated
